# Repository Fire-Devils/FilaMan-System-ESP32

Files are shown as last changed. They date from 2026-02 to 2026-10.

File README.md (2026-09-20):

# FilaMan - Filament Management System

⚠️ **Important: Starting with v3.0.0, this system requires the [FilaMan-System](https://github.com/Fire-Devils/filaman-system) backend. Previous direct integrations (Spoolman, MQTT, Bambu Lab) have been moved to the central FilaMan-System.**

FilaMan is a filament management tool for 3D printing. It uses ESP32 hardware for weight measurement and NFC tag management.
Users can manage filament spools and configure the device via a web interface.
The system integrates seamlessly with the [FilaMan-System](https://github.com/Fire-Devils/filaman-system).

**NEW since 3.3.1:** A reduced version w/o scale is also available. Details can be found in [NFC-only mode](docs/NFC-only_mode_en.md).

Scale

More Images can be found in the [img Folder](/img/)
or my website: [FilaMan Website](https://www.filaman.app)
german explanatory video: [Youtube](https://youtu.be/uNDe2wh9SS8?si=b-jYx4I1w62zaOHU)
Discord Server: [https://discord.gg/my7Gvaxj2v](https://discord.gg/my7Gvaxj2v)

## NEW: Recycling Fabrik

<a href="https://www.recyclingfabrik.com" target="_blank">
    Recycling Fabrik
</a>

FilaMan is supported by [Recycling Fabrik](https://www.recyclingfabrik.com).
Recycling Fabrik will soon offer a FilaMan-compatible NFC tag on their spools. This has the advantage
that the spools can be automatically recognized and imported into the FilaMan-System directly via the FilaMan scale.

**What is Recycling Fabrik?**

Recycling Fabrik is a German company dedicated to developing and manufacturing sustainable 3D printing filament.
Their filaments are made from 100% recycled material from both end customers and industry – for an environmentally conscious and resource-saving future.

More information and products can be found here: [www.recyclingfabrik.com](https://www.recyclingfabrik.com)

---

### Now more detailed informations about the usage: [Wiki](https://github.com/ManuelW77/Filaman/wiki)

### ESP32 Hardware Features
- **Weight Measurement:** Using a load cell with HX711 amplifier for precise weight tracking.
- **NFC Tag Reading/Writing:** PN532 module for reading and writing filament data to NFC tags.
- **OLED Display:** Shows current weight and connection status (WiFi, FilaMan-System).
- **WiFi Connectivity:** WiFiManager for easy network configuration.
- **NFC-Tag NTAG213 NTAG215:** Use NTAG213, better NTAG215 because of enough space on the Tag

### Web Interface Features
- **Real-time Updates:** WebSocket connection for live data updates.
- **NFC Tag Management:**
	- Write filament data to NFC tags.
	- Supports automatic Spool detection in compatible systems.
- **FilaMan-System Integration:**
  - Synchronize spool data with the central backend.
  - Update spool weights automatically.
  - Track NFC tag assignments.

### If you want to support my work, i would be happy to get a coffe

<a href="https://www.buymeacoffee.com/manuelw" target="_blank">Buy Me A Coffee</a>

## Manufacturer Tags Support

🎉 **Exciting News!** FilaMan now supports **Manufacturer Tags** - NFC tags that come pre-programmed directly from filament manufacturers!

### First Manufacturer Partner: RecyclingFabrik

We're thrilled to announce that [**RecyclingFabrik**](https://www.recyclingfabrik.de) will be the **first filament manufacturer** to support FilaMan by offering NFC tags in the FilaMan format on their spools!

**Coming Soon:** RecyclingFabrik spools will include NFC tags that automatically integrate with your FilaMan system, eliminating manual setup and ensuring perfect compatibility.

### How Manufacturer Tags Work

When you scan a manufacturer NFC tag for the first time:
1. **Automatic Brand Detection:** FilaMan recognizes the manufacturer and creates the brand in the FilaMan-System.
2. **Filament Type Creation:** All material specifications are automatically added.
3. **Spool Registration:** Your specific spool is registered with proper weight and specifications.
4. **Future Fast Recognition:** Subsequent scans use fast-path detection for instant weight measurement.

**For detailed technical information:** [Manufacturer Tags Documentation](README_ManufacturerTags_EN.md)

### Benefits for Users
- ✅ **Zero Manual Setup** - Just scan and weigh
- ✅ **Perfect Data Accuracy** - Manufacturer-verified specifications
- ✅ **Instant Integration** - Seamless FilaMan-System compatibility
- ✅ **Future-Proof** - Tags work with any FilaMan-compatible system

## Detailed Functionality

### ESP32 Functionality
- **User Interactions:** The OLED display provides immediate feedback on the system status, including weight measurements and connection status.

### Web Interface Functionality
- **User Interactions:** The web interface allows users to interact with the system, configure the device, and monitor status.
- **UI Elements:** Includes forms for registration, buttons for scale actions, and real-time status indicators.

## Hardware Requirements

### Components (Affiliate Links)
- **ESP32 Development Board:** Any ESP32 variant.
[Amazon Link](https://amzn.to/3FHea6D)
- **HX711 5kg Load Cell Amplifier:** For weight measurement.
[Amazon Link](https://amzn.to/4ja1KTe)
- **OLED 0.96 Zoll I2C white/yellow Display:** 128x64 SSD1306.
[Amazon Link](https://amzn.to/445aaa9)
- **PN532 NFC NXP RFID-Modul V3:** For NFC tag operations.
[Amazon Link](https://amzn.eu/d/gy9vaBX)
- **NFC Tags NTAG213 NTAG215:** RFID Tag
[Amazon Link](https://amzn.to/3E071xO)
- **TTP223 Touch Sensor (optional):** For reTARE per Button/Touch
[Amazon Link](https://amzn.to/4hTChMK)

### Pin Configuration
| Component | ESP32 Pin | ESP32-S3 Pin |
|---|---|---|
| HX711 DOUT | 16 | 5 |
| HX711 SCK | 17 | 6 |
| OLED SDA | 21 | 8 |
| OLED SCL | 22 | 9 |
| PN532 IRQ | 32 | 15 |
| PN532 RESET | 33 | 16 |
| PN532 SDA | 21 | 8 |
| PN532 SCL | 22 | 9 |
| TTP223 I/O | 25 | 7 |

The I2C pins are the Arduino defaults for each chip and are not set explicitly in the code.

**!! ESP32-S3: do not use GPIO19/GPIO20 for the HX711.** These are the native USB data lines (D-/D+) and are wired to the "USB" connector on the DevKitC-1, which makes the HX711 detection unreliable.

**!! Make sure that the DIP switches on the PN532 are set to I2C**
**Use the 3V pin from the ESP for the touch sensor**

Wiring

myWiring
myWiring

*The load cell is connected to most HX711 modules as follows:
E+ red
E- black
A- white
A+ green*

## Software Dependencies

### ESP32 Libraries
- `WiFiManager`: Network configuration
- `ESPAsyncWebServer`: Web server functionality
- `ArduinoJson`: JSON parsing and creation
- `Adafruit_PN532`: NFC functionality
- `Adafruit_SSD1306`: OLED display control
- `HX711`: Load cell communication

### Installation

## Prerequisites
- **Software:**
  - [PlatformIO](https://platformio.org/) in VS Code
  - [FilaMan-System](https://github.com/Fire-Devils/filaman-system) instance
- **Hardware:**
  - ESP32 Development Board
  - HX711 Load Cell Amplifier
  - Load Cell (weight sensor)
  - OLED Display (128x64 SSD1306)
  - PN532 NFC Module
  - Connecting wires

### Step-by-Step Installation
### Easy Installation
1. **Go to [FilaMan Installer](https://www.filaman.app/installer.html)**

2. **Plug you device in and push Connect button**

3. **Select your Device Port and push Intall**

4. **Initial Setup:**
    - Connect to the "FilaMan" WiFi access point.
    - Configure WiFi settings through the captive portal.
    - Access the web interface at `http://filaman.local` or the IP address.

### Compile by yourself
1. **Clone the Repository:**
    ```bash
    git clone https://github.com/ManuelW77/Filaman-System-esp32.git
    cd Filaman-System-esp32
    ```
2. **Install Dependencies:**
    ```bash
    pio lib install
    ```
3. **Flash the ESP32:**
    ```bash
    pio run --target upload
    ```
4. **Initial Setup:**
    - Connect to the "FilaMan" WiFi access point.
    - Configure WiFi settings through the captive portal.
    - Access the web interface at `http://filaman.local` or the IP address.

## Documentation

### Relevant Links
- [FilaMan-System](https://github.com/Fire-Devils/filaman-system)
- [PlatformIO Documentation](https://docs.platformio.org/)

### Tutorials and Examples
- [PlatformIO Getting Started](https://docs.platformio.org/en/latest/tutorials/espressif32/arduino_debugging_unit_testing.html)
- [ESP32 Web Server Tutorial](https://randomnerdtutorials.com/esp32-web-server-arduino-ide/)

## License

This project is licensed under the MIT License. See the [LICENSE](LICENSE) file for details.

## Materials

### Useful Resources
- [ESP32 Official Documentation](https://docs.espressif.com/projects/esp-idf/en/latest/esp32/)
- [Arduino Libraries](https://www.arduino.cc/en/Reference/Libraries)
- [NFC Tag Information](https://learn.adafruit.com/adafruit-pn532-rfid-nfc/overview)

### Community and Support
- [PlatformIO Community](https://community.platformio.org/)
- [Arduino Forum](https://forum.arduino.cc/)
- [ESP32 Forum](https://www.esp32.com/)

## Availability

The code can be tested and the application can be downloaded from the [GitHub repository](https://github.com/ManuelW77/Filaman-System-esp32).

### If you want to support my work, i would be happy to get a coffe
<a href="https://www.buymeacoffee.com/manuelw" target="_blank">Buy Me A Coffee</a>

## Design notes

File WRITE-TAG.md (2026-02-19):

# Dokumentation: RFID/NFC Schreibvorgang (Technischer Guide für KI)

Diese Dokumentation beschreibt den Prozess des Schreibens von RFID/NFC-Tags im FilaMan-System. Sie dient als Referenz für KI-Systeme, um zu verstehen, wie Befehle delegiert, verarbeitet und zurückgemeldet werden.

## 1. Architektur-Übersicht (Asynchrones Modell)

Der Schreibvorgang folgt einem **asynchronen Modell**, um robuster für IoT-Geräte mit unzuverlässigen Netzwerkverbindungen zu sein.

```
┌─────────┐    1. Trigger    ┌─────────┐    2. Fire&Forget  ┌─────────┐
│ Frontend│ ────────────────→│ Backend │ ─────────────────→ │ Device  │
└─────────┘                   └─────────┘                    └─────────┘
       ↑                                                       │
       │                          4. DB-Update                  │
       │    5. Polling ←───────────────────────────────────────┘
       │    (Page Reload)         3. Result-Request
       │
    6. User Feedback
```

### Beteiligte Komponenten:
*   **Frontend:** Initiiert Schreibvorgang und pollt auf Ergebnis (via Page-Reload).
*   **Backend:** Delegiert Befehl an Device und aktualisiert DB, wenn Device Result sendet.
*   **Device:** Führt physischen Schreibvorgang aus und sendet eigenständig Ergebnis zurück.

---

## 2. Der Ablauf (Step-by-Step)

### Schritt 1: Initiierung (Frontend → Backend)
Das Frontend sendet eine Anfrage an das Backend.
- **Endpunkt:** `POST /api/v1/devices/{device_id}/write-tag`
- **Payload:**
  ```json
  {
    "spool_id": 123      // ODER
    "location_id": 45
  }
  ```

### Schritt 2: Fire & Forget (Backend → Device)
Das Backend sendet einen Trigger an das Device:
- **Endpunkt am Gerät:** `POST http://<DEVICE_IP>/api/v1/rfid/write`
- **Timeout:** Das Backend wartet nur kurz (5 Sekunden) auf eine Bestätigung, dass der Trigger empfangen wurde. Es wartet NICHT auf das RFID-Ergebnis.
- **Response an Frontend:** Das Backend antwortet sofort mit:
  ```json
  {
    "success": true,
    "message": "Schreibvorgang wurde gestartet. Bitte Tag bereit halten..."
  }
  ```

### Schritt 3: Physische Verarbeitung (Device)
Das Device:
1. Empfängt den Trigger.
2. Startet den RFID-Schreibvorgang.
3. Sendet **eigenständig** das Ergebnis an das Backend.

### Schritt 4: Ergebnis an Backend (Device → Backend)
Das Device sendet das Ergebnis nach Abschluss des Schreibvorgangs:
- **Endpunkt:** `POST /api/v1/devices/rfid-result`
- **Authentifizierung:** `Authorization: Device <TOKEN>`
- **Payload:**
  ```json
  {
    "success": true,
    "tag_uuid": "E2801234...",
    "spool_id": 123,    // Optional: ID der Spule
    "location_id": 45   // Optional: ID des Ortes
  }
  ```

### Schritt 5: Datenbank-Update (Backend)
Das Backend empfängt das Ergebnis:
- Bei `spool_id`: Update von `spools.rfid_uid`.
- Bei `location_id`: Update von `locations.identifier`.

### Schritt 6: Frontend-Polling
Das Frontend pollt periodisch (alle 2 Sekunden) durch erneutes Laden der Spulen/Locations-Liste:
- Sobald die `rfid_uid` oder `identifier` gesetzt ist → Erfolgsmeldung.
- Nach max. 30 Versuchen (60 Sekunden) → Timeout-Meldung.

---

## 3. API-Referenz

### 3.1 Trigger Endpoint (Frontend → Backend)

**`POST /api/v1/devices/{device_id}/write-tag`**

Startet den Schreibvorgang auf dem Device. Antwortet sofort (Fire & Forget).

**Request:**
```json
{
  "spool_id": 123,      // Optional
  "location_id": 45     // Optional (eins von beiden muss gesetzt sein)
}
```

**Response (sofort):**
```json
{
  "success": true,
  "message": "Schreibvorgang wurde gestartet. Bitte Tag bereit halten..."
}
```

### 3.2 Result Endpoint (Device → Backend)

**`POST /api/v1/devices/rfid-result`**

Das Device ruft diesen Endpoint auf, nachdem der Schreibvorgang abgeschlossen ist.

**Header:**
- `Authorization: Device <TOKEN>`

**Request:**
```json
{
  "success": true,
  "tag_uuid": "E2801234...",
  "spool_id": 123,      // Optional
  "location_id": 45,    // Optional
  "error_message": null  // Optional: Fehlermeldung falls success=false
}
```

**Response:**
```json
{
  "status": "ok",
  "message": "Spool updated" // oder "Location updated"
}
```

---

## 4. Anforderungen an das Device

### 4.1 Endpoint für Trigger
Das Device muss folgenden Endpoint unterstützen:
- **URL:** `http://<DEVICE_IP>/api/v1/rfid/write`
- **Method:** POST
- **Content-Type:** application/json

**Verhalten:**
- Empfängt den Trigger (spool_id oder location_id)
- Startet den RFID-Schreibvorgang
- Sendet NICHT sofort die tag_uuid zurück (Fire & Forget)

### 4.2 Eigenständiges Senden des Ergebnisses
Nach dem Schreibvorgang muss das Device eigenständig das Ergebnis an das Backend senden:

```cpp
// Pseudocode für ESP32
void sendResultToBackend(String tagUuid, int locationId) {
    HTTPClient http;
    http.begin("http://<BACKEND_IP>/api/v1/devices/rfid-result");
    http.addHeader("Content-Type", "application/json");
    http.addHeader("Authorization", "Device " + deviceToken);
    
    String json = "{\"success\": true, \"tag_uuid\": \"" + tagUuid + "\", \"location_id\": " + locationId + "}";
    http.POST(json);
    http.end();
}
```

### 4.3 Authentifizierung
Das Device muss sich mit dem Token authentifizieren:
- Header: `Authorization: Device <TOKEN>`
- Der Token ist der gleiche, der auch für Heartbeat verwendet wird.

---

## 5. Zusammenfassung für die KI-Logik

1.  **Fire & Forget:** Der Trigger-Request vom Backend zum Device ist asynchron. Das Backend antwortet sofort.
2.  **Push-Modell:** Das Device ist für das Senden des Ergebnisses verantwortlich (nicht das Warten auf eine Antwort).
3.  **Polling:** Das Frontend erkennt den Erfolg durch das Pollen/Neuladen der Daten (prüfen auf gesetzte `rfid_uid` oder `identifier`).
4.  **Keine offene Verbindung:** Es gibt keine 180-Sekunden-Wartezeit mehr auf eine offene HTTP-Verbindung.

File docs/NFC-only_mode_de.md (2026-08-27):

# NFC-only Modus

## Beschreibung
Es kann praktisch sein, ein kleines Gerät in der Nähe deines Desktop-Computers zu haben, wenn du neue Spulen in deine Datenbank hinzufügst.
So kannst du sofort NFC-Tags für sie schreiben. Da keine Waage erforderlich ist (das Gewicht einer neuen Spule ist in der Regel bekannt), ist es sinnvoll, auf diese Funktion zu verzichten, um einen kleineren Formfaktor zu erreichen.

FilaLite_no_scale

## Bedienung

Bevor du das NFC-only Terminal verwenden kannst, musst du es in der `FilaMan System App` registrieren, wie bei jeder anderen Waage auch.

### Tag schreiben
Hauptzweck ist das Schreiben neuer NFC-Tags.

Du startest den Schreibvorgang in der `FilaMan System App` (Web-GUI). Dann wählst du dein NFC-Gerät aus und folgst den Anweisungen auf dem Display.

### Tag lesen
Das Gerät kann Tags zwar lesen, sinnvolle Anwendungsfälle sind jedoch ohne Waage eingeschränkt.
Du kannst trotzdem eine Spule identifizieren und ihr einen Standort mit dem entsprechenden Standort-Tag zuweisen.

Aber ehrlich gesagt: der Hauptzweck des NFC-only Gerätes ist **TAG SCHREIBEN**.

## NFC-only Modus

Beim Start versucht der ESP32, den HX711 (Verstärker) zusammen mit einem angeschlossenen Loadcell-Sensor zu erkennen. Wenn das gelingt, startet er im Normalmodus mit voller Funktionalität.

Andernfalls schaltet er in den **NFC-only Modus**!

Statt einer Gewichtsanzeige zeigt das Display eine Bereitschaftsmeldung. Zusätzlich ist das Waagensymbol in der oberen Zeile durchgestrichen.

Ready Prompt

## Aufbau / Installation
### Hardware
Die Verkabelung der Hardware ist gleich wie bei der originalen, voll ausgestatteten FilaMan-Waage. Es gibt nur 3 Unterschiede:

- Kein HX711 angeschlossen (und natürlich keine Loadcell)
- Kein Tastensensor (ohne Waage ist kein Tarieren nötig)
- optional: 10k Pull-up-Widerstand an Pin 16 (RX2)

Der Pull-up-Widerstand ist nicht zwingend erforderlich, erhöht aber die Zuverlässigkeit beim Erkennen eines fehlenden HX711. Ohne Pull-up-Widerstand sollte es aber ebenfalls funktionieren.

Schaltplan mit Pull-Up

| Komponente | ESP32 Pin |
| ---- | ---- |
| 10k Pull-up  | 16 |
| | 17 |
| OLED SDA | 21 |
| OLED SCL | 22 |
| PN532 IRQ | 32 |
| PN532 RESET  | 33 |
| PN532 SDA | 21 |
| PN532 SCL | 22 |

#### PN532
- **!! Stelle sicher, dass die DIP-Schalter des PN532 auf I2C gestellt sind**
- Verbinde `VCC` mit 5V

#### OLED
- Verbinde `VCC` mit 3,3V

#### 10k Widerstand (optional)
- Verbinde den Widerstand mit PIN 16 (wo normalerweise der DOUT des HX711 angeschlossen wäre) und 5V

### Software
Folge den Anweisungen in der [Hauptdokumentation](../README.de.md#schritt-für-schritt-installation).

Du benötigst Version 3.3.1 oder neuer für eine funktionierende Hardware-Erkennung und den NFC-only Modus.

## Druck-Dateien
[STLs](../_3D%20Print%20Files/FilaMan_Lite/)

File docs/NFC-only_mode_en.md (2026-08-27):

# NFC-only mode

## Description
It may be convenient to have a small device near your desktop computer when adding new spools to your database.
So you are able to write NFC-tags for them right away. Since there is no need for a scale (the weight of a new
spool should be well known), it is pleasant to leave the scale functionality out in advance of a smaller footprint.

FilaLite_no_scale

## Usage

Before you can use the NFC-only device, you have to register it to your FilaMan System App as
you would do with any regular scale device.

### Tag Writing
 Its main purpose is to write new NFC tags.

 You start the writing process from within the FilaMan System App (Web GUI). You than select
 your NFC device and follow the instructions on the device display.

### Tag Reading
Although the device is fully capable of tag reading, its use cases are limited due to the lack of a scale.
But you can still identify a spool and assign it to a location with the according location tag.

But to be honest: the main purpose of the NFC-only device is **TAG WRITING**.

## NFC-only mode

During startup, the ESP32 tries to detect the HX711 (amplifier) together with a connected
loadcell sensor. If successful it starts into normal mode with full functionality.

Otherwise it switches in **NFC-only mode!**

Instead of a weight reading the display shows a ready prompts. Additionally the scale icon
in the top row is crossed out.

Ready Prompt

## Build / Installation
### Hardware
The wiring of the hardware is the same as the original, fully equipped FilaMan scale. There are only 3 differences:

- No HX711 connected (also no loadcell of course)
- No touch sensor (without scale there is no need to tare)
- optional: 10k pull-up resistor on Pin 16 (RX2)

The pull-up resistor is not mandatory, but for good measure. It makes it more reliable to
detect a missing hx711. But it should also work w/o the pull-up resistor.

Schaltplan mit Pull-Up

| Component	  | ESP32 Pin |
| ---- | ---- |
| 10k pull-up | 16 |
| 	  | 17 |
| OLED SDA	  | 21 |
| OLED SCL. | 22 |
| PN532 IRQ | 32 |
| PN532 RESET |	33 |
| PN532 SDA	  | 21 |
| PN532 SCL	  | 22 |

#### PN532
- !! Make sure that the DIP switches on the PN532 are set to I2C
- Connect `VCC` to 5V

#### OLED
- Connect `VCC` to 3.3V

#### 10k Resistor (optional)
- Connect to PIN 16 (where normally the DOUT of the HX711 would connect to) and 5V

### Software
Follow the instructions in the [main readme](../README.md#step-by-step-installation).

You need version 3.3.1 or later for a working hardware recognition and NFC-only mode.

## Print Files
[STLs](../_3D%20Print%20Files/FilaMan_Lite/)

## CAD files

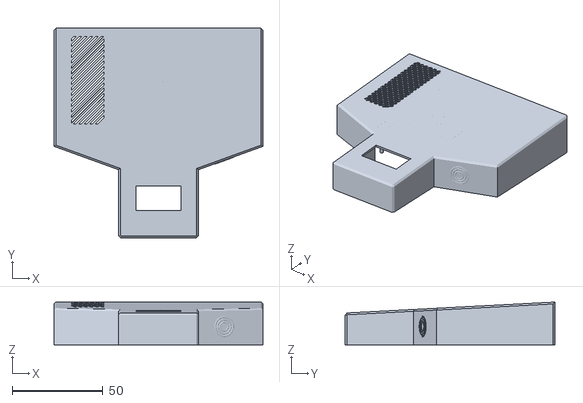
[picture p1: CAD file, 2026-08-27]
_3D Print Files/FilaMan_Lite/FilaLite Top low.stl
115.0 x 115.3 x 23.6

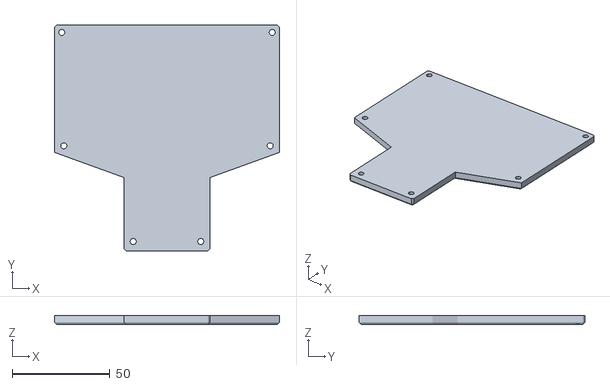
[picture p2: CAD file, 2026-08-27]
_3D Print Files/FilaMan_Lite/FilaLite Bottom.stl
115.0 x 115.3 x 4.50

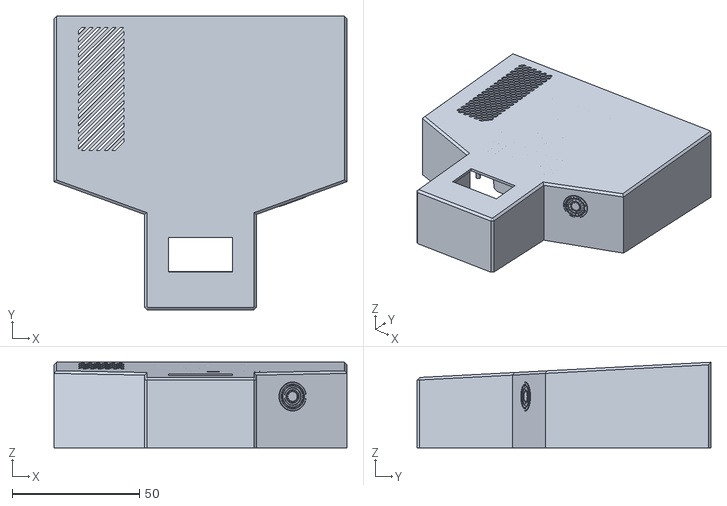
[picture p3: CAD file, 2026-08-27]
_3D Print Files/FilaMan_Lite/FilaLite Top high.stl
115.0 x 115.3 x 33.6

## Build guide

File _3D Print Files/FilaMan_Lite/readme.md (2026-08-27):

- The **low version** has the same dimensions as the casing of [FilaMan Revamped](https://makerworld.com/de/models/1258715-filaman-revamped-nfc-based-spoolman-scale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). 
  But because of the missing scale the distance between the PN532 and a NFC tag placed on the marked area might be too narrow, what leads to weak/failed connection.

- The **high version** takes account of this but makes the casing 10mm higher

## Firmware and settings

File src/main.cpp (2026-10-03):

#include <Arduino.h>
#include <Wire.h>
#include <WiFi.h>
#include <freertos/FreeRTOS.h>
#include <freertos/task.h>

#include "wlan.h"
#include "config.h"
#include "website.h"
#include "api.h"
#include "display.h"
#include "nfc.h"
#include "scale.h"
#include "esp_task_wdt.h"
#include "commonFS.h"
#include "lang.h"

bool mainTaskWasPaused = 0;
uint8_t scaleTareCounter = 0;
bool touchSensorConnected = false;
bool booting = true;

// ##### SETUP #####
void setup() {
  Serial.begin(115200);

  uint64_t chipid;

  chipid = ESP.getEfuseMac(); //The chip ID is essentially its MAC address(length: 6 bytes).
  Serial.printf("ESP32 Chip ID = %04X", (uint16_t)(chipid >> 32)); //print High 2 bytes
  Serial.printf("%08X\n", (uint32_t)chipid); //print Low 4bytes.

  // Initialize SPIFFS
  initializeFileSystem();

  // Load language setting from NVS (before display init)
  loadLanguage();

  // Start Display
  setupDisplay();

  // WiFiManager
  initWiFi();

  // Webserver
  setupWebserver(server);

  // FilaMan API
  initFilaman();

  // NFC Reader
  startNfc();

  // Touch Sensor
  pinMode(TTP223_PIN, INPUT_PULLUP);
  if (digitalRead(TTP223_PIN) == LOW)
  {
    Serial.println("Touch Sensor is connected");
    touchSensorConnected = true;
  }

  // Scale
  start_scale(touchSensorConnected);
  if (scaleConnected){
    scaleTareRequest = true;
  }

  // WDT initialisieren mit 10 Sekunden Timeout
  bool panic = true; // Wenn true, löst ein WDT-Timeout einen System-Panik aus
  esp_task_wdt_init(10, panic);

  booting = false;
  oledShowProgressBar(6, NUM_SETUP_STEPS, DISPLAY_BOOT_TEXT, tr(STR_INIT_DONE));

  // Aktuellen Task (loopTask) zum Watchdog hinzufügen
  esp_task_wdt_add(NULL);

  if ( !scaleConnected ) {
    // Clear Display after Boot
    oledDisplayText(tr(STR_NOSCALE_PROMPT));
  }
}


/**
 * Safe interval check that handles millis() overflow
 * @param currentTime Current millis() value
 * @param lastTime Last recorded time
 * @param interval Desired interval in milliseconds
 * @return True if interval has elapsed
 */
bool intervalElapsed(unsigned long currentTime, unsigned long &lastTime, unsigned long interval) {
  if (currentTime - lastTime >= interval || currentTime < lastTime) {
    lastTime = currentTime;
    return true;
  }
  return false;
}

unsigned long lastWeightReadTime = 0;
const unsigned long weightReadInterval = 1000; // 1 second

unsigned long lastFilamanHeartbeatTime = 0;
unsigned long lastWifiCheckTime = 0;
unsigned long lastTopRowUpdateTime = 0;

uint8_t weightSend = 0;
int16_t lastWeight = 0;

// Button debounce variables
unsigned long lastButtonPress = 0;
const unsigned long debounceDelay = 500; // 500 ms debounce delay

unsigned long lastConnErrorShowTime = 0;
const unsigned long connErrorShowInterval = 10000; // Show connection error every 10 seconds if exists

// ##### PROGRAM START #####
void loop() {
  unsigned long currentMillis = millis();

  // Handle connection errors (not registered or not connected)
  if (intervalElapsed(currentMillis, lastConnErrorShowTime, connErrorShowInterval)) {
      if (!filamanRegistered && oledCanUpdate(DISPLAY_PRIORITY_WARNING)) {
          oledShowConnectionError(tr(STR_NOT_REGISTERED), WiFi.localIP().toString());
          oledSetPriority(DISPLAY_PRIORITY_WARNING, 3000);
          mainTaskWasPaused = true;
      } else if (!filamanConnected && oledCanUpdate(DISPLAY_PRIORITY_WARNING)) {
          oledShowConnectionError(tr(STR_API_CONN_LOST), WiFi.localIP().toString());
          oledSetPriority(DISPLAY_PRIORITY_WARNING, 3000);
          mainTaskWasPaused = true;
      } else if ( !scaleConnected ){
          // everything fine again: without scale manual clearing of the error msg is needed
          oledDisplayText(tr(STR_NOSCALE_PROMPT));
      }
  }

  // Überprüfe den Status des Touch Sensors (nur wenn Waage vorhanden)
  if (scaleConnected && touchSensorConnected && digitalRead(TTP223_PIN) == HIGH && currentMillis - lastButtonPress > debounceDelay)
  {
    lastButtonPress = currentMillis;
    scaleTareRequest = true;
    oledResetActivityTimer(); // Wake display on touch press
  }

  // Überprüfe regelmäßig die WLAN-Verbindung
  if (intervalElapsed(currentMillis, lastWifiCheckTime, WIFI_CHECK_INTERVAL))
  {
    checkWiFiConnection();
  }

  // Periodic display update
  if (intervalElapsed(currentMillis, lastTopRowUpdateTime, DISPLAY_UPDATE_INTERVAL))
  {
    oledShowTopRow();
    oledCheckSleep(); // Put display to sleep if timeout elapsed
  }

  // WebSocket Cleanup alle 5 Sekunden (häufiger als vorher)
  // Tote Clients können WiFi-Ressourcen blockieren
  static unsigned long lastWsCleanup = 0;
  if (currentMillis - lastWsCleanup >= 5000) {
    ws.cleanupClients();
    lastWsCleanup = currentMillis;
  }

  // Periodic FilaMan heartbeat
  if (intervalElapsed(currentMillis, lastFilamanHeartbeatTime, FILAMAN_HEARTBEAT_INTERVAL))
  {
    sendHeartbeatAsync();
  }

  // If scale is not calibrated, only show a warning
  if (scaleConnected && !scaleCalibrated)
  {
    // Do not show the warning if the calibratin process is onging
    if(!scaleCalibrationActive){
      oledDisplayText(tr(STR_SCALE_NOT_CALIBRATED));
      vTaskDelay(pdMS_TO_TICKS(1000));
    }
  }

  if (scaleConnected && scaleCalibrated)
  {
    // Ausgabe der Waage auf Display
    // Block weight display during NFC write operations and higher-priority display messages
    if(pauseMainTask == 0 && !nfcWriteInProgress && oledCanUpdate(DISPLAY_PRIORITY_STATUS))
    {
      // Use filtered weight for smooth display, but still check API weight for significant changes
      int16_t displayWeight = getFilteredDisplayWeight();
      if (mainTaskWasPaused || (weight != lastWeight && (nfcReaderState == NFC_IDLE || tagProcessed)))
      {
        oledShowWeight((abs(displayWeight) < 2) ? 0 : displayWeight);
        oledSetPriority(DISPLAY_PRIORITY_STATUS, 0);  // Weight can always be overwritten
      }
      mainTaskWasPaused = false;
    }
    else
    {
      mainTaskWasPaused = true;
    }

    // Während eines expliziten Scan-Requests darf kein regulärer Wiegevorgang
    // an das Backend gesendet werden.
    if (scanRequestActive) {
      weightCounterToApi = 0;
      weightSend = 0;
      lastWeight = weight;
    }


    // Wenn Timer abgelaufen und nicht gerade ein RFID-Tag geschrieben wird
    if (!scanRequestActive && currentMillis - lastWeightReadTime >= weightReadInterval && nfcReaderState < NFC_WRITING)
    {
      lastWeightReadTime = currentMillis;

      // Prüfen ob das Gewicht gleich bleibt und dann senden
      if (abs(weight - lastWeight) <= 2 && weight > 5)
      {
        weightCounterToApi++;
        // Show stable weight feedback when approaching send threshold
        if (weightCounterToApi == 3 && nfcReaderState == NFC_READ_SUCCESS && !tagProcessed && weightSend == 0) {
          oledShowProgressBar(2, 4, tr(STR_SPOOL_TAG), tr(STR_WEIGHT_STABLE));
          oledSetPriority(DISPLAY_PRIORITY_INFO, 1000);
        }
      }
      else
      {
        // Show visual feedback when tag is present and weight is unstable
        if (weightCounterToApi > 0 && nfcReaderState == NFC_READ_SUCCESS && !tagProcessed && weightSend == 0) {
          oledShowProgressBar(1, 4, tr(STR_SPOOL_TAG), tr(STR_WEIGHING));
          oledSetPriority(DISPLAY_PRIORITY_INFO, 1000);
        }
        weightCounterToApi = 0;
        weightSend = 0;
      }

      lastWeight = weight;

      // Wenn ein Tag erkannt wurde und das Gewicht stabil ist (4+ seconds), an FilaMan senden
      if (!scanRequestActive && weightCounterToApi > 3 && weightSend == 0 && nfcReaderState == NFC_READ_SUCCESS && tagProcessed == false)
      {
        tagProcessed = true;

        // Check if it's a Bambu tag - if so, send only UUID without spoolId
        if (isBambuTag) {
          sendWeightAsync(0, activeTagUuid, weight);
          Serial.println("Bambu weight queued for FilaMan (UUID only)");
        } else {
          // Normal NTAG: send spoolId + UUID
          int sId = activeSpoolId.toInt();
          sendWeightAsync(sId, activeTagUuid, weight);
          Serial.println("Weight queued for FilaMan");
        }
        weightSend = 1;

        // Feedback to user
        oledShowProgressBar(3, 4, tr(STR_SPOOL_TAG), tr(STR_SENDING));
        oledSetPriority(DISPLAY_PRIORITY_ACTION, 2000);
      }

      // Handle successful tag write
      if (!scanRequestActive && nfcReaderState == NFC_WRITE_SUCCESS && tagProcessed == false)
      {
        tagProcessed = true;

        // Only send weight if a valid spoolId exists (spool tag, not location tag)
        if (activeSpoolId.length() > 0 && activeSpoolId != "0") {
          int sId = activeSpoolId.toInt();
          sendWeightAsync(sId, activeTagUuid, weight);
          weightSend = 1;
          Serial.println("Weight queued for FilaMan after spool tag write");

          // Feedback to user
          oledShowProgressBar(3, 4, tr(STR_TAG_WRITTEN), tr(STR_SENDING));
          oledSetPriority(DISPLAY_PRIORITY_ACTION, 2000);
        } else {
          // Location tag written - no weight to send
          Serial.println("Location tag written successfully - no weight send needed");
        }
      }
    }
  }
  esp_task_wdt_reset();
}

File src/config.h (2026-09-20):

#ifndef CONFIG_H
#define CONFIG_H

#include <Arduino.h>

#define NVS_NAMESPACE_API                   "api"
#define NVS_KEY_FILAMAN_URL                "filamanUrl"
#define NVS_KEY_FILAMAN_TOKEN              "filamanToken"
#define NVS_KEY_FILAMAN_REGISTERED         "registered"

#define NVS_NAMESPACE_SCALE                 "scale"
#define NVS_KEY_CALIBRATION                 "cal_value"
#define NVS_KEY_AUTOTARE                    "auto_tare"

#define NVS_NAMESPACE_SETTINGS             "settings"
#define NVS_KEY_LANGUAGE                    "language"
#define NVS_KEY_OLED_SLEEP                  "oled_sleep"
#define NVS_KEY_WIFI_TXPOWER                "wifi_txpwr"
#define SCALE_DEFAULT_CALIBRATION_VALUE     430.0f;

#define OLED_RESET                          -1      // Reset pin # (or -1 if sharing Arduino reset pin)
#define SCREEN_ADDRESS                      0x3CU   // See datasheet for Address; 0x3D for 128x64, 0x3C for 128x32
#define SCREEN_WIDTH                        128U
#define SCREEN_HEIGHT                       64U
#define SCREEN_TOP_BAR_HEIGHT               16U
#define SCREEN_PROGRESS_BAR_HEIGHT          12U
#define DISPLAY_BOOT_TEXT                   "FilaMan"

#define WIFI_CHECK_INTERVAL                 15000U
#define DISPLAY_UPDATE_INTERVAL             1000U
#define FILAMAN_HEARTBEAT_INTERVAL          60000U

#define NUM_SETUP_STEPS                     6   // 0:Display 1:WiFi 2:Web-Server 3:API 4:NFC 5:Scale 6:<finished>

extern const uint8_t PN532_IRQ;
extern const uint8_t PN532_RESET;

extern const uint8_t LOADCELL_DOUT_PIN;
extern const uint8_t LOADCELL_SCK_PIN;
extern const uint8_t calVal_eepromAdress;
extern const uint16_t SCALE_LEVEL_WEIGHT;

extern const uint8_t TTP223_PIN;

extern const uint8_t OLED_TOP_START;
extern const uint8_t OLED_TOP_END;
extern const uint8_t OLED_DATA_START;
extern const uint8_t OLED_DATA_END;

extern String filamanUrl;
extern String filamanToken;
extern bool filamanRegistered;

extern const uint8_t webserverPort;



extern const unsigned char wifi_on[];
extern const unsigned char wifi_off[];
extern const unsigned char cloud_on[];
extern const unsigned char cloud_off[];

extern const unsigned char icon_failed[];
extern const unsigned char icon_success[];
extern const unsigned char icon_transfer[];
extern const unsigned char icon_loading[];

extern uint8_t rfidTaskCore;
extern uint8_t rfidTaskPrio;

extern uint8_t rfidWriteTaskPrio;

extern uint8_t scaleTaskCore;
extern uint8_t scaleTaskPrio;

extern uint16_t defaultScaleCalibrationValue;
extern uint16_t oledSleepTimeout;

// WLAN-Sendeleistung in 0.1 dBm (195 = 19.5dBm). Siehe txPowerFromDeciDbm() in wlan.cpp.
extern int16_t wifiTxPowerDeciDbm;
#endif

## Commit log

2026-02-11 feat: add printer model selection and handling in Bambu integration
2026-02-19 Remove Bambu integration: delete Bambu-related source files and references, including MQTT setup and credential management. Clean up configuration and main application logic to eliminate unused varia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
2026-02-19 Refactor API to FilaMan: Update API structure, remove Spoolman references, and implement new FilaMan functions for device registration, heartbeat, weight, and location updates. Adjust web server rout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
2026-02-19 Add setup page for device registration and configuration
    - Created a new HTML file for device setup with a form for API URL and registration code.
    - Implemented JavaScript for handling registration and displaying status messages.
    - Updated upgrade and WiFi pages to include navigation to the new setup page.
    - Refactored display functions to improve readability and consistency.
    - Replaced occurrences of `oledShowMessage` with `oledDisplayText` for uniformity.
    - Updated WebSocket handling in the upgrade and WiFi pages for better connection management.
    - Adjusted delays in various functions to use `pdMS_TO_TICKS` for better timing accuracy.
    - Removed unused routes and cleaned up the website code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
    [display.cpp, main.cpp, nfc.cpp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]
2026-02-20 Refactor JSON error handling in NFC write request: simplify error response and delegate request handling to NFC task.
    [website.cpp]
2026-02-20 Add connection error handling to display: show error messages for registration and API connection issues
    [display.cpp, main.cpp, wlan.cpp]
2026-02-20 fix: update response handling in setupWebserver to use beginResponse method
    [website.cpp]
2026-02-21 fix: improve connection error handling and display logic in main loop
    [main.cpp, wlan.cpp]
2026-02-21 fix: ensure weight is only sent for valid spool tags in loop
    [main.cpp]
2026-02-21 fix: reduce delay times for API tasks and NFC scanning to improve responsiveness
    [main.cpp, nfc.cpp]
2026-05-05 Added configuration for esp32-s3
2026-05-28 feat: enhance RFID tag detection with NDEF support and improved error handling
    [nfc.cpp]
2026-05-28 fix: disable WiFiManager auto-reconnect to prevent connection storms
    [wlan.cpp]
2026-05-28 fix: skip fast-path detection for known spools when a scan request is active
    [nfc.cpp]
2026-05-28 feat: implement scan request handling with timeout and error reporting
    [main.cpp, nfc.cpp]
2026-08-09 fix: update release flow
2026-08-12 fix: update JSON handling to support spool_id and sm_id interchangeably
    [nfc.cpp]
2026-08-21 fix(config): restore ESP32 Dev Board pin numbers, gate S3 pins behind CONFIG_IDF_TARGET_ESP32S3
    PR #14 (0f43f22) unconditionally replaced the classic ESP32 Dev Board
    pin numbers for PN532 (NFC), HX711 (scale) and TTP223 (touch) with the
    ESP32-S3 values in the single shared src/config.cpp, even though the
    esp32dev build environment (used for all standard-hardware releases)
    still links against it unchanged. This caused nfc.begin() to talk to
    the wrong physical pins on ESP32 Dev Board hardware, producing a
    watchdog reset during NFC init and a subsequent bootloop.
    Verified via objdump on both compiled config.cpp.o that esp32dev now
    resolves to 32/33/16/17/25 and esp32-s3-devkitc-1 to 15/16/19/2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
2026-08-21 fix(nfc): pulse PN532 RSTPDN before begin()
    Adafruit_PN532::begin() drives the reset line too briefly for some
    modules to reliably leave powerdown (~1ms LOW/2ms HIGH internally),
    which then makes getFirmwareVersion() return 0 right after begin() and
    startNfc() report "Kann kein RFID Board finden". Add an explicit
    50ms/200ms reset pulse before begin(), shared via pulsePn532Reset()
    so startNfc() and the interface recovery path in ntag2xx_WriteNDEF()
    don't duplicate the timing.
    Adopts the fix from PR #24 (credit: rsantamaria01), refactored into a
    shared helper per review feedback (duplicate pulse code flagged by the
    automated Copilot review on that PR).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
    [nfc.cpp]
2026-08-21 Revert "fix(nfc): pulse PN532 RSTPDN before begin()"
    This reverts commit 27e16c3d1b2a7ff299b9a18e756c6e496f95b9f9.
    [nfc.cpp]
2026-08-21 fix(net): unblock AsyncTCP during device registration, max TX power, roaming diagnostics
    Three independent improvements to the WiFi/webserver stability:
    1. /api/register called registerDevice() directly inside the AsyncWebServer
    body handler. That function does a blocking HTTPClient POST with a 5s
    timeout, freezing the AsyncTCP task and tearing down every in-flight HTTP
    and WebSocket connection. It now goes through the existing apiQueue /
    filamanApiTask machinery: the endpoint answers 202 immediately (or 503 if
    the queue is full, which would otherwise leave the UI waiting forever) and
    the outcome is pushed to the browser as a "registerResult" WebSocket
    message. setup.ht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
    [website.cpp, wlan.cpp]
2026-08-25 added STLs for FilaMan Lite case (without scale)
    [FilaLite Bottom.stl, FilaLite Top high.stl, FilaLite Top low.stl]
2026-08-25 Add Druck-Dateien section to NFC-only mode documentation
    Added section for print files and STL resources.
2026-08-25 Fix link to STL files in NFC-only mode documentation
2026-08-25 Add print files section to english NFC-only mode documentation
    Added section for print files with STL links.
2026-09-20 Make WiFi TX power configurable, document ESP32-S3 pins
    The transmit power was hardcoded to 19.5 dBm. Some setups need a lower
    value (device right next to the AP, weak 3.3V rail), so it is now a user
    setting instead of a per-chip constant.
    - wlan.cpp: load/save/apply TX power (0.1 dBm steps, NVS key wifi_txpwr,
    default 195), re-applied on GOT_IP so it survives a reconnect
    - website.cpp: /api/wifi-power GET/POST with validation
    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
2026-09-30 style: fix indentation in main loop
    [main.cpp]
